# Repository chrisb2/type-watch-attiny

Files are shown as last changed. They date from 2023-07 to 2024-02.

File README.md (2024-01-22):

# type-watch
This project is based on an [ATtiny85](https://www.microchip.com/en-us/product/ATtiny85) MCU and uses two piezoelectric sensors under a keyboard to sense harsh typing and flashes a LED when a strong keystroke is detected. This feedback allows the user to train themselves to type gently, thus avoiding occupational overuse syndrome (OOS).

The program can use any MCU which supports the Arduino language.

The piezo sensors are [Sparkfun Piezo Elements](https://www.sparkfun.com/products/10293) and are connected at connector _J3_.

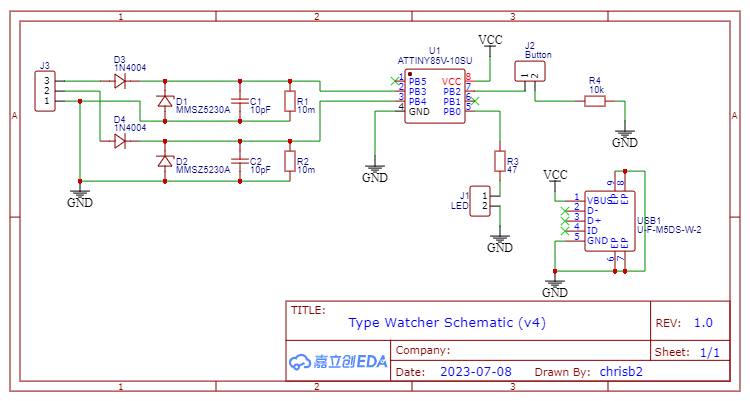
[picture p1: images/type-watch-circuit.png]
circuit diagram


The Gerbers and BOM for the PCB are in the _gerbers_ directory.
pcb

The PCB is 55 * 8.3mm and is designed to fit inside a 9.5 * 9.5mm square PVC tube.

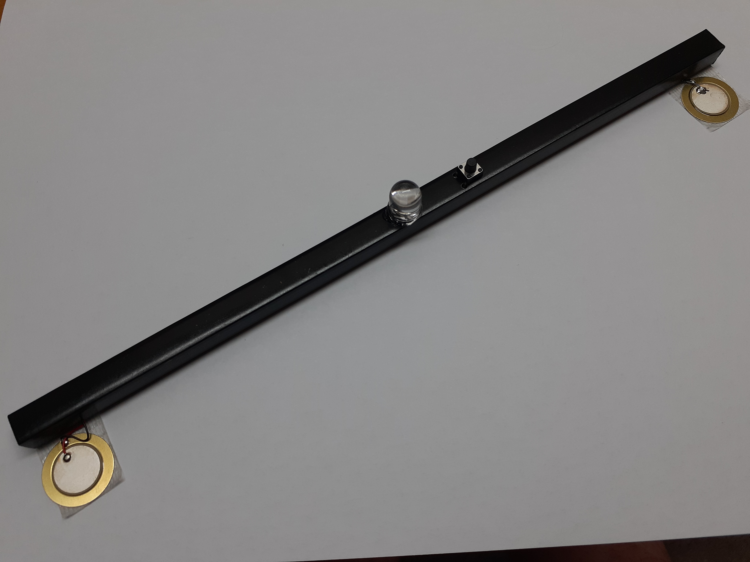
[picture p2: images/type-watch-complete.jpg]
Complete Device


The piezoelectric sensors are placed under each back foot of the keyboard. 

The threshold can be adjusted between the limits in the program by pressing the button and is stored in EEPROM so that it persists over restarts.

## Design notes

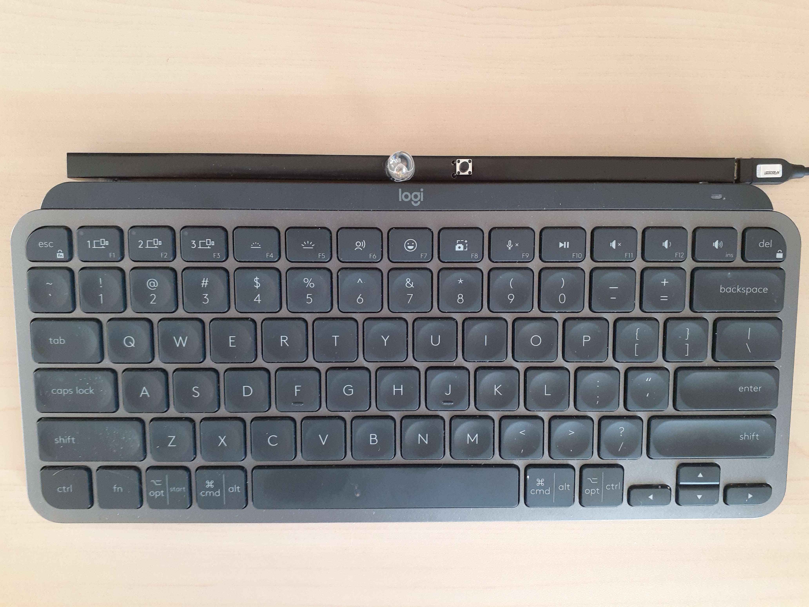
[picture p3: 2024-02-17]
images/complete-with-keyboard.jpg

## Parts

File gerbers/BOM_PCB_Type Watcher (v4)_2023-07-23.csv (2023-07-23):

ID | Name | Designator | Footprint | Quantity | Manufacturer Part | Manufacturer | Supplier | Supplier Part
1 | ATTINY85V-10SU | U1 | SOIC-8_L5.3-W5.3-P1.27-LS8.0-BL | 1 | ATTINY85V-10SU | MICROCHIP(美国微芯) | LCSC | C152192
2 | 10pF | C1,C2 | C1206 | 2 | GCM31A5C3A100JX01D | muRata(村田) | LCSC | C437499
3 | MMSZ5230A_R1_00001 | D1,D2 | SOD-123_L2.7-W1.6-LS3.8-RD | 2 | MMSZ5230A_R1_00001 | PANJIT(强茂) | LCSC | C391550
4 | 1N4004_C727080 | D3,D4 | SMA_L4.4-W2.8-LS5.4-RD | 2 | 1N4004 | TWGMC(台湾迪嘉) | LCSC | C727080
5 | 10m | R1,R2 | R1206 | 2 |  |  | LCSC | C2933773
6 | 47 | R3 | R1206 | 1 |  |  | LCSC | C326800
7 | 10k | R4 | R1206 | 1 |  |  | LCSC | C2907370
8 | U-F-M5DS-W-2 | USB1 | MICRO-USB-SMD_MICRO-USB-A15 | 1 | U-F-M5DS-W-2 | 韩国韩荣 | LCSC | C145789

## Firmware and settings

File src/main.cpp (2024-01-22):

#include <Arduino.h>
#include <Bounce2.h>
#include <ezLED.h>
#include <EEPROM.h>

// Threshold control values in millivolts
const int minThreshold = 1200;
const int maxThreshold = 2200;
const int stepSize = 100;
int threshold = 0;

// Pins
const int piezoPin1 = A2;
const int piezoPin2 = A3;
const int buttonPin = 2;

const int eepromAddr = 0;

// On period for LED flash
const int flashDelay = 200;
// Convert adc value to millivolts
const float mvFactor = 4.88f;
// Number of ADC readings to average
const int numReadings = 3; 


Bounce button = Bounce();
ezLED led(DISPLAY_LED);

int readPiezo(int pin);
void printMillivolts(int v1, int v2);
void printThreshold(int threshold);
int readThreshold();
void writeThreshold(int currThreshold);

void setup() {
  button.attach(buttonPin, INPUT_PULLUP);
  button.interval(5);
  led.blinkInPeriod(100, 100, 1000);
  threshold = readThreshold();
#ifdef UNO
  Serial.begin(9600);
  Serial.println("Begin");
#endif
}

void loop() {
  led.loop();

  button.update();
  if (button.fell()) {
    threshold += stepSize;
    if (threshold > maxThreshold) {
      threshold = minThreshold;
      led.blinkNumberOfTimes(50, 50, 4);
    } else {
      led.blinkNumberOfTimes(100, 100, 1);
    }
    writeThreshold(threshold);
#ifdef UNO
    printThreshold(threshold);
#endif
  }

  int piezo1 = readPiezo(piezoPin1);
  int piezo2 = readPiezo(piezoPin2);
  if (piezo1 > threshold || piezo2 > threshold) {
    led.blinkNumberOfTimes(flashDelay, flashDelay, 1);
#ifdef UNO
    printMillivolts(piezo1, piezo2);
#endif
  }
}

int readPiezo(int pin) {
  int sum = 0;
  for(int i = 0; i < numReadings; i++) {
    sum += analogRead(pin);
  }
  int average = sum / numReadings;
  
  // convert the average analog reading to millivolts
  return (int)(average * mvFactor); 
}

int readThreshold() {
  int val = EEPROM.read(eepromAddr);
  return (val * stepSize) + minThreshold;
}

void writeThreshold(int currThreshold) {
  int val = (currThreshold - minThreshold) / stepSize;
  EEPROM.write(eepromAddr, val);
}

#ifdef UNO
void printMillivolts(int v1, int v2) {
  Serial.print(v1);
  Serial.print(", ");
  Serial.println(v2);
}

void printThreshold(int threshold) {
    Serial.println(threshold);
}
#endif

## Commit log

2023-07-16 Switch to ezLED library
2023-07-17 Switch to ResponsiveAnalogRead ADC library
2023-07-23 Add Gerbers and BOM
    [BOM_PCB_Type Watcher (v4)_2023-07-23.csv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]
2023-10-14 Revert to using basic ADC reads as ResponsiveRead reduces sensitivity too much
    [main.cpp]
2024-01-20 Adjust threadholds
